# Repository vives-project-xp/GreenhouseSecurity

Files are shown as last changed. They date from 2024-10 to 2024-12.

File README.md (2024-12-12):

# Greenhouse Security

Op de site campus Brugge Xavarianenstraat komt een serre van 3x6m. Daarbij komt later ook nog een Tiny-house. Dit alles als IoT incubator voor project experience.   
Ons project zal zorgen voor de security en beveiliging van de serre. We maken hiervoor gebruik van bewakings camera's en een toegangs controle systeem.

# Inhoud
- [GreenhouseSecurity](#greenhousesecurity)
  - [Inhoud](#inhoud)
  - [Team](#team)
  - [Features](#features)
  - [Planning](#planning)
    - [Sprint 1](#sprint-1)
    - [Sprint 2](#sprint-2)
    - [Sprint 3](#sprint-3)
    - [Sprint 4](#sprint-4)
  - [Installatie Software](#installatie-software)
    - [Axis Camera Station](#axis-camera-station)
    - [Python](#python)
    - [Raspberry Pi](#raspberry-pi)
  - [Research](#research)
      - [Toegangssystemen](#toegangssystemen)
        - [NFC](#nfc)
        - [Authenticator](#authenticator)
        - [Biometrisch](#biometrisch)
      - [Camera's](#cameras)
        - [Axis](#axis)
        - [Stappenplan](#stappenplan)
        - [Privacy](#privacy)
      - [Project Affiche](#project-affiche)
  - [Het Project](#het-project)
        - [Installatie Camera's](#installatie-cameras)
        - [Installatie 360 Dome Camera](#installatie-360-dome-camera)
          - [3D-prints](#3d-prints)
        - [Installatie Fixed Camera](#installatie-fixed-camera)
          - [Montage](#montage)
      - [Installatie Toegangssysteem](#installatie-toegangssysteem)
        - [Code](#code)
  - [Integratie](#integratie)
  - [Pictogram:](#pictogram)
  - [Links](#links)
  - [Erkenningen](#erkenningen)
  - [BOM-Lijst](#bom-lijst)
  - [Research](#research)
# Team

- [Luca De Clerck](https://github.com/LucaClrk)  
- [Xander Claessens](https://github.com/xanderClaessens)   
- [Domien Verstraete](https://github.com/Belgianwafflecorp)

# Features
-  Security beelden van de serre
-  Mogelijkheid om security beelden overal te bekijken
-  Toegang tot serre controleren
-  Mogelijkheid om de deuren te sluiten
-  Geauthenticeerde toegang

# Planning
Onze planning kan je in detail bekijken op [Notion](https://www.notion.so/Project-Management-Tasks-Projects-Planning-15a7c97a744380f28060f6c136deb173?pvs=4).  
Maar hier zullen wij in grote lijnen alles plaatsen wat wij hebben gedaan en wat we zullen doen.  
## Planner
- ### Sprint 1
  - Architectuur document opgesteld
  - Axis Software testen
  - Camera functies testen
- ### Sprint 2
  - VM aanmaken
  - Code schrijven voor Raspberry Pi
  - Elektronisch schema uittekenen
- ### Sprint 3
  - Affiche maken
  - Starten PowerPoint
  - Motion Detection uittesten
  - Netwerk in orde stellen(VLAN)
  - Overleg wetgeving camera's
  - 3D-stukken printen
- ### Sprint 4
  -  Camera's installeren in serre
  -  Toegangssysteem installeren in serre
  -  Programma toegang afwerken
  -  Camera's en Raspberry Pi verbinden met netwerk
  -  Notificaties versturen bij motion detection

# Installatie Software
### Axis Camera Station
Ga naar de [Axis Camera station 5](https://www.axis.com/products/axis-camera-station/download) pagina om de nieuwste versie te downloaden. Hiermee ben je in staat de Axis camera's te beheren.
Het is belangrijk om de AXIS Camera Station Client MSI installer te installeren.  
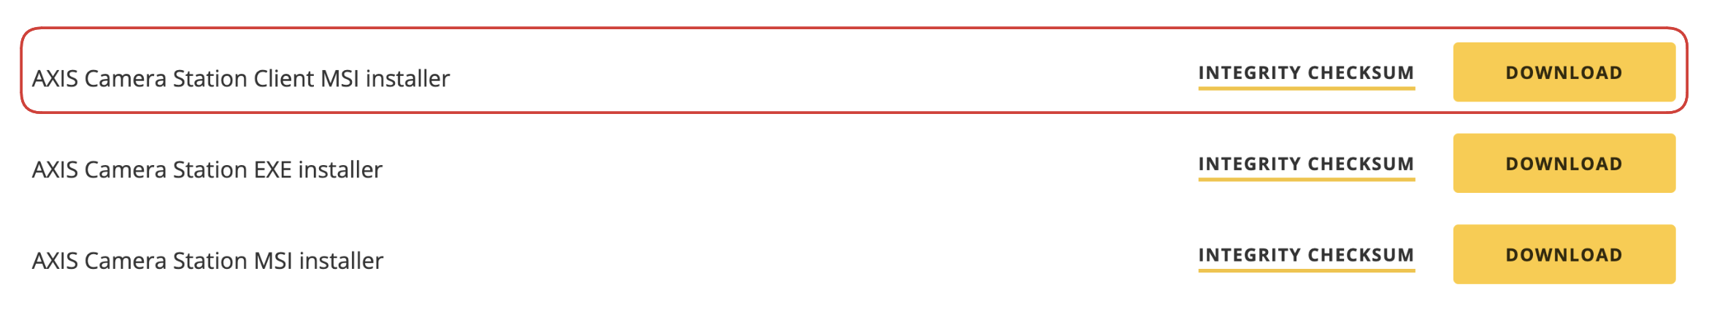
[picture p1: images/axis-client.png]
axis


### Python
Python kan je programmeren via [Visual Studio Code](https://code.visualstudio.com/download) of een andere IDE naar keuze. Bij gebruik van Visual Studio Code kan je de Python extensie installeren om zo te beginnen aan je Python programma.  
je drukt op de knop Extensions aan de linkerkant van je scherm. Dan krijg je een scherm van al de extensies.    
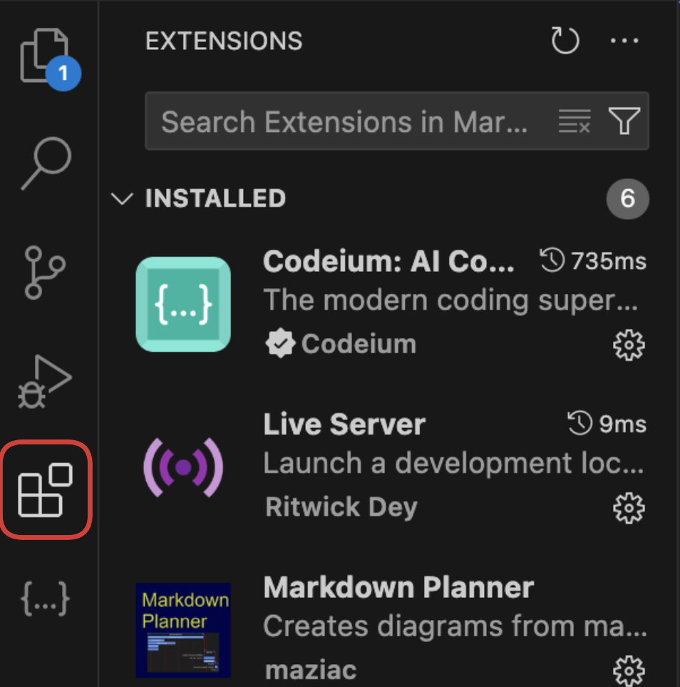
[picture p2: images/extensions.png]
  
Hierna kan je Python in typen in de zoekbalk. Dit geeft een lijst met alle extensies die te maken hebben met Python. Je zal de aangeduide versie willen installeren.  
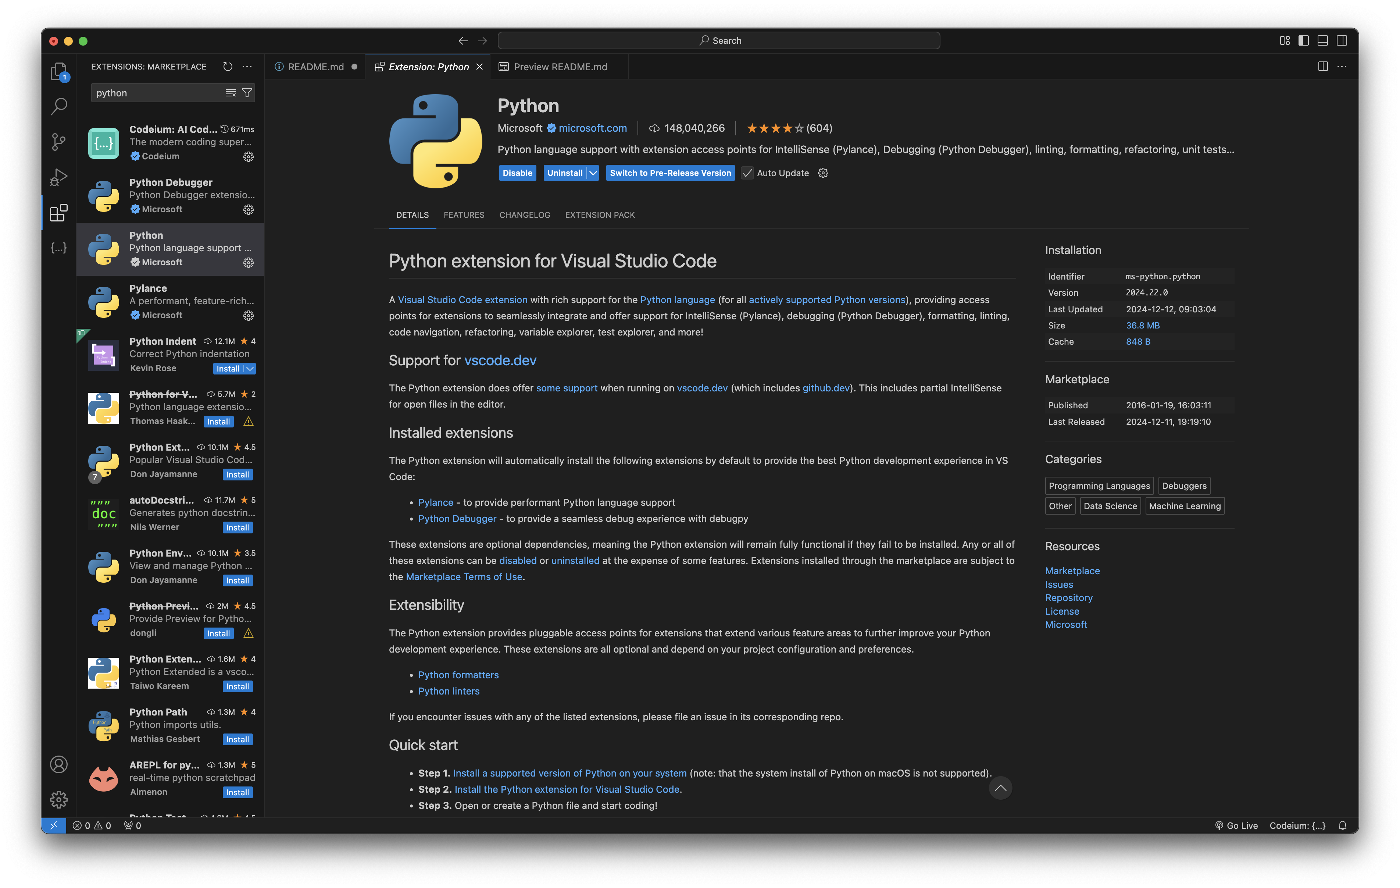
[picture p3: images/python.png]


### Raspberry Pi
Eerst en vooral moet je een [Raspberry Pi](https://www.raspberrypi.com/software/) aankopen. Als het mogelijk is een model 3 of hoger. Op de website heb je dan de mogelijkheid om de versie te installeren die past bij uw systeem.  
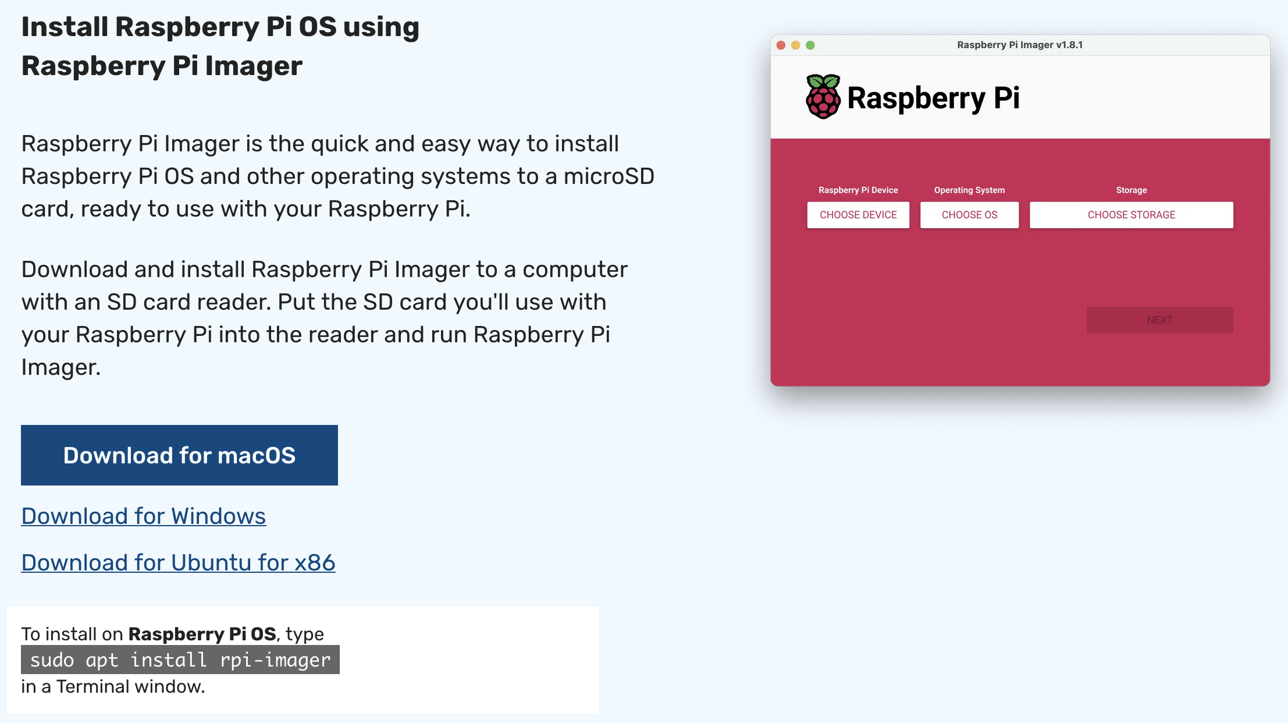
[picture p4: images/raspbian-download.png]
raspberry-pi
  
Hierna kan je via een SD kaart de [Raspberry Pi OS](https://www.raspberrypi.com/software/) installeren op je bordje. 
Via HDMI of DP, te zien welk bordje je hebt, kan je dan verbinden met de Raspberry Pi. 

# Research
  - ## Toegangsystemen:
    - ### NFC  
       NFC staat voor Near-Field Communication. Zoals de naam zelf verklapt is dit een manier om communicatie in te schakelen over een kleine afstand. Een set van communicatie protocollen maken het mogelijk om communicatie tussen elektronische apparaten in staat te stellen over een afstand van max 4cm.  
          Dit werkt met enerzijds een zend-/ontvangapparaat met een voeding en anderzijds een object met een chip en antenne, zoals een kaart, die gezamenlijk een NFC-tag hebben. De tag heeft geen voeding nodig omdat hij inductie energie ontvangt van het apparaat.  
          NFC wordt in veel toepassingen gebruikt. Denk aan betalingtransacties,sleutelhanger voor toegangscontrole...  

      NFC is dus een mogelijke optie voor toegangscontrole tot de serre. Je kan dan met een NFC-tag de serre openen. Bijvoorbeeld aan de hand van je GSM en een simpele RFID-chip.  
    - ### Authenticator  
        Een authenticator is ook een manier om toegangscontrole toe te passen. Denk aan de google authenticator die je constant codes geeft die veranderen. Dit zorgt voor een veilige manier van toegangscontrole omdat je "wachtwoord" tot de serre voor iedereen anders is en constant verandert. Ook is er geen nood aan een kaart of dergelijke, die je mogelijks kan verliezen.  
    - ### Biometrisch  
        Biometrie betekent letterlijk "meten van de levenden" en verwijst in een hele brede zin naar de studie van levende wezens. Wij zullen deze studies toepassen om een biometrisch toegangscontrole systeem te maken.  
        Biometrie kan je "meten", denk aan je vingerafdruk, irispatroon, gelaatstrekken of DNA. Wij zullen niet zo ver gaan als DNA, maar iets zoals je vingerafdruk kan zeker zorgen voor een goeie beveiliging.
        Een toegangskaart of tag zoals bij NFC kan je verliezen, je vinger zal je niet zo rap verliezen.
        Jammer genoeg zullen zij niet aan biometrie doen omdat deze gegevens moeten opgeslaan worden. Door de privacy wet mogen wij dit soort gegevens niet opslaan.

- ## Camera's
    - ### Axis   
      Wij werden Axis camera's aangeboden van de opleiding Elektronica-ICT. Axis is een Zweedse manufacturer die zich spezialiseert in het verkopen van camera's, access control en netwerk audio apparaten voor bedrijven. We werken dus met een high end camera systeem die bedoelt is voor industriële bedrijven. Deze camera's komen met geïntegreerde software en software van Axis zelf die we kunnen gebruiken voor heel wat doeleinden.  
      Met de software zijn we in staat om beelden te streamen, op te nemen en zelfs motion detection toe te passen.
    - ### Stappenplan  
      Het is heel gemakkelijk om deze apparaten operationeel te maken.  
      Installeer eerst de Axis Software die u nodig acht voor het gebruik van de camera's. Wij hebben hiervoor Axis Camera Station 5 gebruikt.  
      Plug de camera's in via Ethernet in je netwerk en na een paar minuten zouden deze moeten verschijnen in de applicatie.  
      In de applicatie kan u dan kiezen wat u met deze camera's wilt doen. Het is wel belangrijk dat je op hetzelfde netwerk zit als de camera's.
    - ### Privacy  
      Omtrent de wet van de privacy zijn er heel wat wettem over het gebruik van camera's. Uiteraard moeten wij met al deze wetten rekening houden tijdens het maken van dit project.  
      Om dit te verduidelijken kan u een kijkje nemen in ons document "[info](./Wetgeving/info.md)".

    - ### Melding wanneer iemand het gebied betreed of inlogt
        - SMS
        - Mail

# Project Affiche
Voor het project werden wij gevraagd om een affiche te maken. Deze affiche bevat de titel van het project, een korte beschrijving, de vaardigheden die werden gebruikt voor het project te realiseren een paar foto's. Met dit affiche is het de bedoeling om ons project zo aantrekkelijk mogelijk te maken en gemakkelijk uit te leggen over wat dit gaat.  

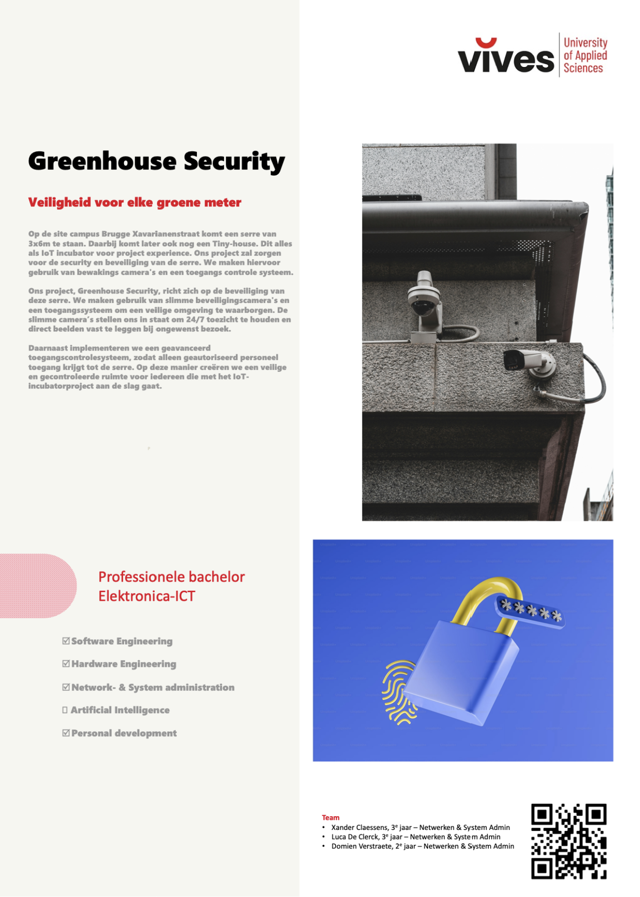
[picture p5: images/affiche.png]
affiche
  

# Het Project  
Na dat het research is gebeurd, kunnen we beginnen met het project. Omdat de serre er in het begin van het semester nog niet stond konden we niet onmiddellijk een oplossing bedenken van hoe we de camera in de serre zouden plaatsen, of hoe we het toegangsysteem zouden opzetten in de serre. Maar dit heeft ons niet tegengehouden en we zijn toch begonnen met ideeën hiervoor.
## Camera's
We zijn begonnen met de camera's te testen via de Axis Camera Station software. Hier waren we er ook al snel achter gekomen dat er motion detection kon toegepast worden met deze software. Samen met Home Assistant hadden we dan de mogelijkheid om mails te sturen wanneer de camera beweging detecteerde. Om het netwerk niet te belasten moest er een aparte VLAN aangemaakt worden voor de camera's. Naast dit moest er ook een VM aangemaakt worden die ervoor zorgt dat we deze camera beelden overal kunnen bekijken. Deze VM moet dan logischer wijs ook in VLAN 12 terecht komen.  

Na dat de serre geplaatst werd konden we dan ook beginnen nadenken over hoe we deze camera in de serre konden plaatsen.
### Installatie Camera's  

-  #### Installatie 360 Dome Camera
      Om de camera in de serre te plaatsen hebben wij 3D-stukken aangevraagd. Deze 3D-prints hebben wij zelf getekend in AutoDesk Inventor.  

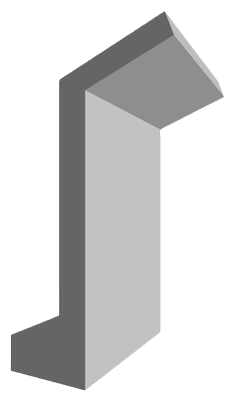
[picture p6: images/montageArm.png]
      
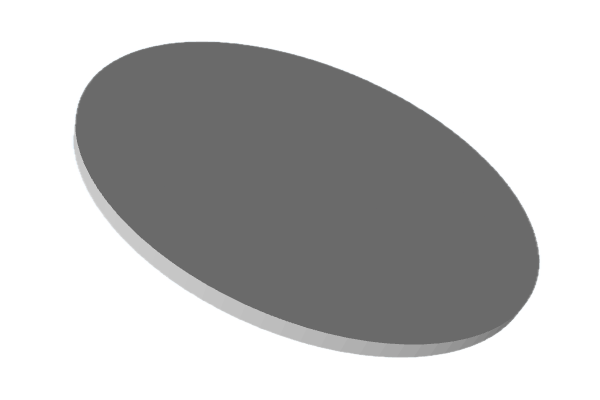
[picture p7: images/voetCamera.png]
          
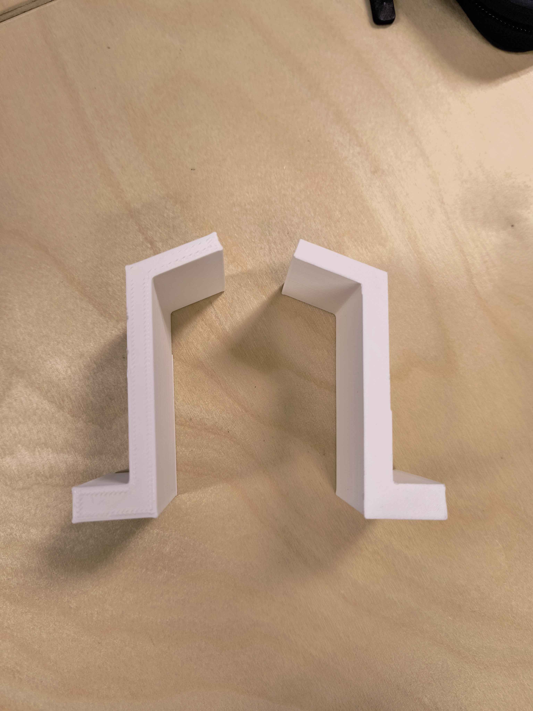
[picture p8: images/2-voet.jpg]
        
      
      De arm stukken zullen we gebruiken om te monteren aan het dak. De voet kunnen we dan monteren aan deze armen. Na deze installatie kunnen we gemakkelijk de camera aan de voet monteren voor een stabiele installatie.  

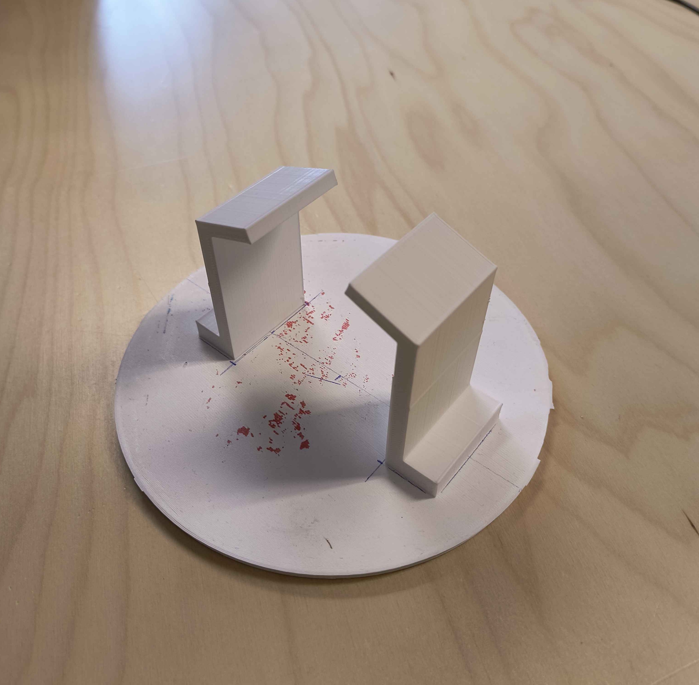
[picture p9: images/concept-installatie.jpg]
        
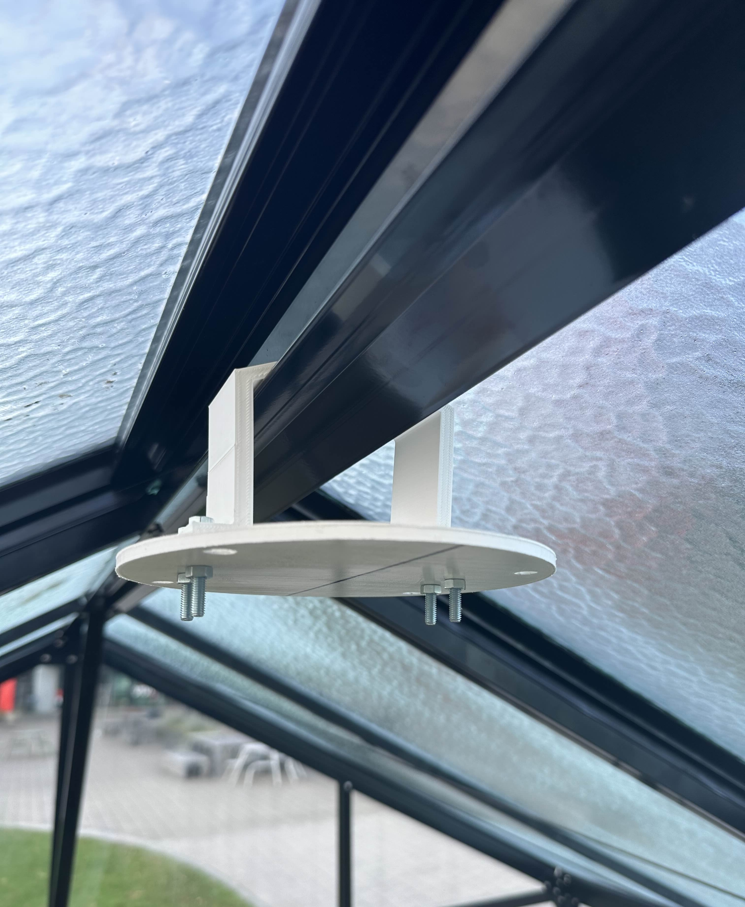
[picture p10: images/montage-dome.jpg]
      

-  ### Installatie Fixed Camera
    De fixed camera komt op het dak te staan. Om dit te doen hebben we iets stevig nodig om de camera te monteren. Dit stuk zal ook tegen de diverse weersomstandigheden bestand moeten zijn.  
    Daarom hebben wij geopteerd voor bandijzer. Dit is een plaat ijzer met gaten in die buigbaar en waar je kan door boren.   
    Dit bandijzer hebben wij zo geplooid dat dit op de railing van het dak zal komen. Dit zal er zo uitzien :

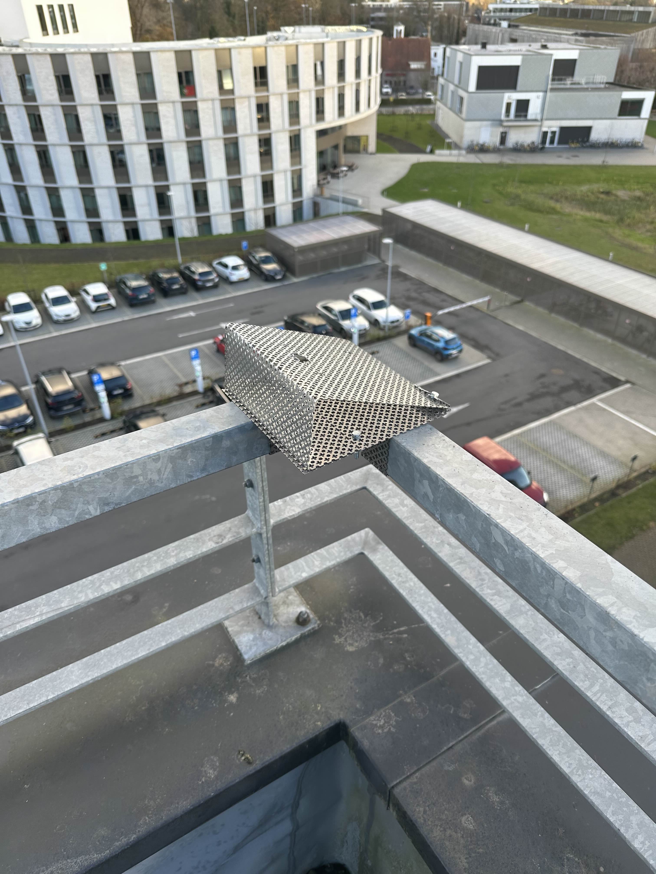
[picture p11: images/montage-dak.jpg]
bandijzer
      

Na dat de installaties gebeurd zijn, konden we beginnen met de beelden op een scherm te krijgen in het lokaal. Hiervoor hebben we een PC geboot met Windows 10. Hierop installeerden we dan de Axis software waardoor we de camera beelden te zien kregen.  
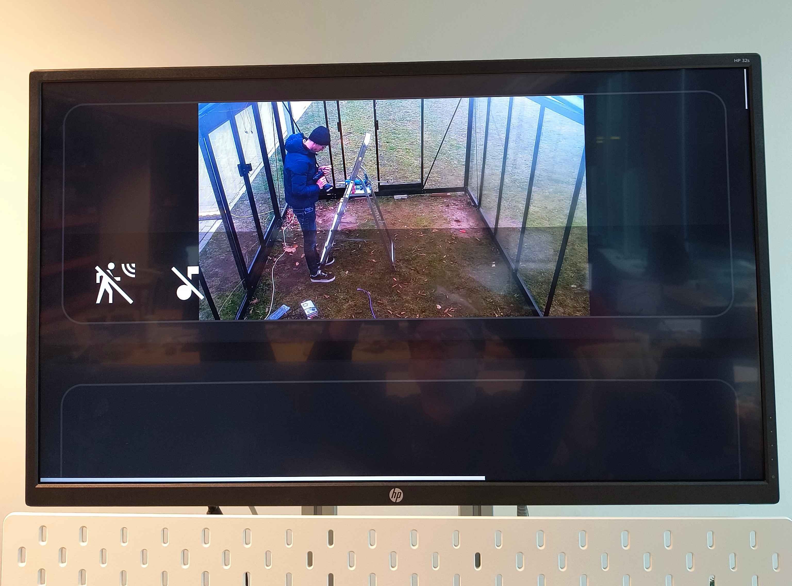
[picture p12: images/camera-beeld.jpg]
  

Na commentaar van het hoofd van de infrastructuur werd ons verteld dat de camera op het dak weg moest. Hier hebben wij jammer genoeg dus geen beelden van.

## Toegangsysteem
Na de verschillende toegangsystemen te bestuderen hebben wij besloten om een authenticator te gebruiken. Met de Google authenticator krijg je een code, deze code moet dan met een numeriek ingegeven worden. Na dat deze code ingegeven wordt worden de deuren geopend.
### Installatie Toegangssysteem
  Om het toegangssysteem te installeren gebruiken wij 4 solenoïden die als een slot werken voor de deuren. Een solenoide is een pin die geactiveerd wordt als deze onder spanning komt te staan.
  Hij doet dat aan de hand van een veer.  
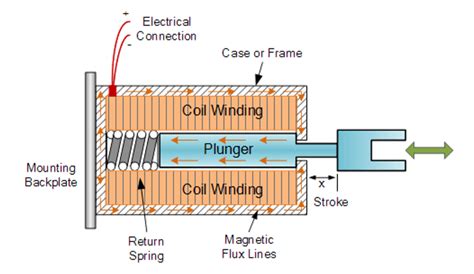
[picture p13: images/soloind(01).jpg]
    
  De deuren van de serre zijn schuifdeuren, hierdoor hebben wij geopteerd om deze sloten telkens aan de onderkant te plaatsen. Hierdoor kan je de deur niet openen als het slot niet naar beneden is.
  De solenoïden worden aangestuurd via een relais. Je kunt ervoor kiezen om deze normally closed of normally open te hebben. Wij zouden opteren voor normally closed zodat ze niet constant onder spanning komen te staan.  
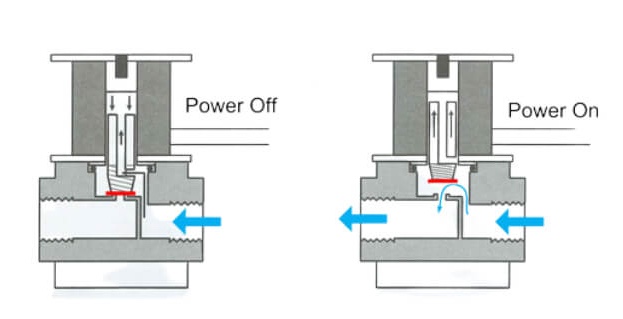
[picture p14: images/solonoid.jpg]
solonoid
    
  Na dat de code dan ingegeven wordt, wordt via de elektronische schakeling de pinnen geschakeld waardoor de deuren geopend worden.

### Code
  In de [Setup](./Documenten/setup.md) file Kan je lezen welke libraries u zal nodig hebben om het programma te schrijven.  
  Met dit programma gebruiken we user input van het numeriek toegangsbordje. Met deze input kunnen we verifiëren als deze persoon wel toegang heeft tot de serie en kunnen we de deuren gesloten of geopend zetten.  
  Als je de volledige code wil bekijken kan je dit vinden in de [Code](Code/Authenticator/) folder.  

# Integratie
De serre bestaat niet alleen voor het project Security. Er zijn nog heel wat andere projecten die ook rond de serre gaan. Het is dan belangrijk om ervoor te zorgen dat al deze projecten samen kunnen werken.  
Hiermee wordt dan bedoelt dat deze projecten op hetzelfde netwerk werken, elkaar niet storen en als 1 geheel werkt.  
In deze topic zullen we uitleggen hoe wij ervoor zorgen dat ons project geïntegreerd is zodat het kan samenwerken met alle andere projecten.  

Het project Home-Assistant zal ervoor zorgen dat er een netwerk aanwezig is in de serre. Dit netwerk zal ons in staat stellen om de gebruikte camera's voor het project te verbinden met dit netwerk.  
Door dit te doen heeft Home-Assistant de mogelijkheid om de camera beelden te bekijken op hun applicatie. Op deze manier is ons project geïntegreerd met de andere projecten, want home-assistant zorgt voor de integratie van alle projecten.

# Pictogram:
Verplicht pictogram met aanduiding dat er camera bewaking aanwezig is.
Dit staat in het Koninklijk besluit dat dit zo moet (zie links voor meer info). 

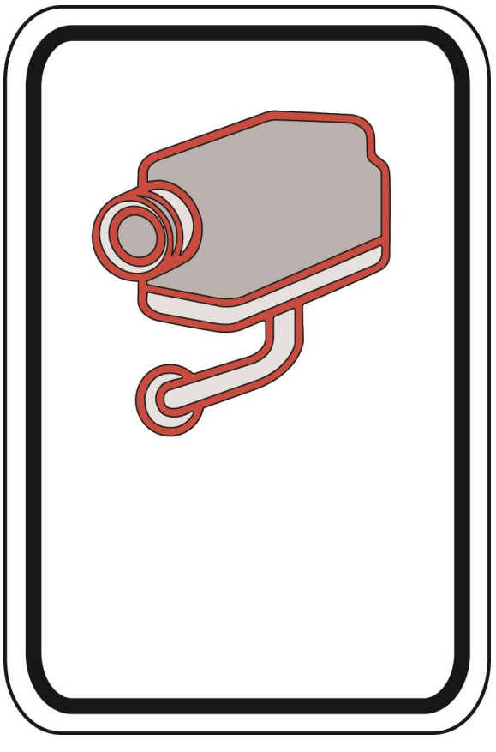
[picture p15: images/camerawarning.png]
camera sticker


# Links
- [Info](https://acd.eu/producten/r308-xh-blackline/)
- [Koninklijk Besluit](https://www.besafe.be/sites/default/files/2022-08/ar_pictogramme_-_version_coordonnee_avec_modif_2020.pdf) 
- [Info](https://www.besafe.be/nl/bewakingscamera/pictogram)
- [Klein pin slot](https://www.credexalarmsystems.eu/nl/eb-004-conas-electric-bolt-lockfor-automatic-doors-failsafe.html)
- [2-kanaals 3V relais module](https://www.kiwi-electronics.com/nl/2-kanaals-3v-relais-module-20106?search=relais)
- [Koninklijk Besluit](https://www.besafe.be/sites/default/files/2022-08/ar_pictogramme_-_version_coordonnee_avec_modif_2020.pdf) 
- [Info](https://www.besafe.be/nl/bewakingscamera/pictogram)
- [Klein pin slot](https://www.credexalarmsystems.eu/nl/eb-004-conas-electric-bolt-lockfor-automatic-doors-failsafe.html)
- [Keypad info](https://learn.adafruit.com/matrix-keypad?view=all)
- [Axis OS](https://www.axis.com/products/axis-camera-station/download) 

# Erkenningen

- [Info](https://acd.eu/producten/r308-xh-blackline/)
- [Koninklijk Besluit](https://www.besafe.be/sites/default/files/2022-08/ar_pictogramme_-_version_coordonnee_avec_modif_2020.pdf) 
- [Pictogram](https://www.besafe.be/nl/bewakingscamera/pictogram)
- [Klein Pin Slot](https://www.credexalarmsystems.eu/nl/eb-004-conas-electric-bolt-lockfor-automatic-doors-failsafe.html)

# BOM-Lijst

| Beschrijving | Hoeveelheid | Prijs (€) |
|---|---|---|
| Raspberry pi | 1 | 61,95 |
| Nummeriek | 1 | 7,34 |
| Pictogram | 1 | 2,39 |
| Push-pull solenoids | 4 | 47,80 |
| Montage stukken  | 4 | 9,16 |
| Kables | 7 | 12.39 |
| Aftakdoos | 1 | 12.79 |
| Relais module | 1 | 11.90 |
| Tapbout met moer | 1 | 7,99 |
| Fastener met draadeind | 1 | 3,99 |
| **Total Price** | - |  |

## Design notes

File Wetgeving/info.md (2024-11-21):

##  Belangrijkste stappen die we moeten ondernemen om camera's te mogen ophangen:
### We zitten met 2 situaties waar we rekening mee moeten houden en die zijn:
    - camera wetgeving
    - camera op werkplaats

- Doelstelling vastleggen: De school moet een duidelijke doelstelling hebben voor de camerabewaking. Dit kan bijvoorbeeld het beveiligen van eigendommen, het beschermen van personen, of het voorkomen van diefstal of vandalisme zijn. De camera’s mogen niet gebruikt worden voor toezicht op personeel of studenten zonder een geldige reden.

- Camerabewakingswet: In België is de Camerabewakingswet van toepassing. Volgens deze wet moet de school de plaatsing van de camera's melden bij de Lokale Politie en moet ze een aangifte doen via het [E-loket](www.aangiftecamera.be) van de FOD Binnenlandse Zaken.

- GDPR (General Data Protection Regulation): Camerabeelden kunnen als persoonsgegevens worden beschouwd. De school moet de GDPR-regels volgen en ervoor zorgen dat de gegevensverwerking rechtmatig, transparant en in overeenstemming met de wet gebeurt. Dit houdt in dat:

- De school een verwerkingsregister bijhoudt.
Camerabeelden alleen worden bewaard voor de noodzakelijke duur (meestal maximaal 30 dagen).
Er een verwerkersovereenkomst is als de beelden door een extern bedrijf worden beheerd.
Informatieplicht (bordje hangen): De school moet mensen die het gebouw betreden informeren over de camerabewaking. Dit gebeurt door het ophangen van een pictogram dat aangeeft dat er camera's hangen, met daarbij de contactgegevens van de verantwoordelijke voor de verwerking van de beelden.

- Raadpleging van de ondernemingsraad of vakbonden: Als de camera's ook personeelsleden zullen opnemen, moet de school de ondernemingsraad of personeelsvertegenwoordiging raadplegen, aangezien dit betrekking heeft op de werkvloer.

- Vergunningen: In de meeste gevallen is er geen specifieke vergunning nodig voor het ophangen van bewakingscamera's, maar dit kan verschillen per gemeente. Het is verstandig om dit te controleren bij de lokale overheid.

### Samenvatting van de stappen:
1. Aangifte doen bij de politie (voor elke camera).
2. Overleg met werknemers (voor camera’s op de werkplek).
3. Pictogrammen en informatieborden plaatsen.
4. Recht op toegang tot beelden waarborgen.
5. Veilige opslag en bewaartermijn van maximaal 1 maand.
6. Informatieplicht naar betrokkenen (GDPR).

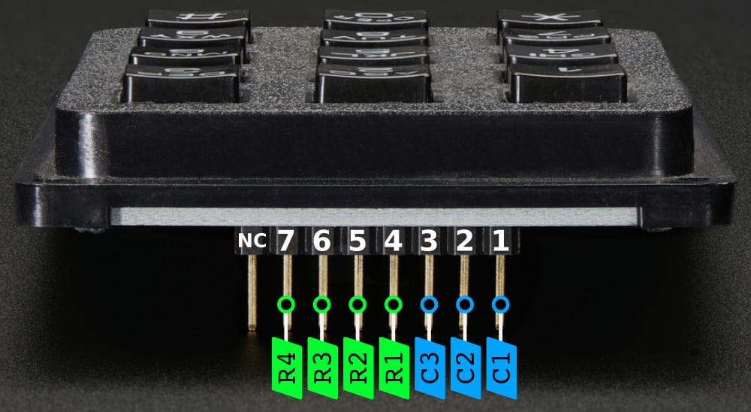
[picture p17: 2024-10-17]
images/KeypadPinOuts.jpg

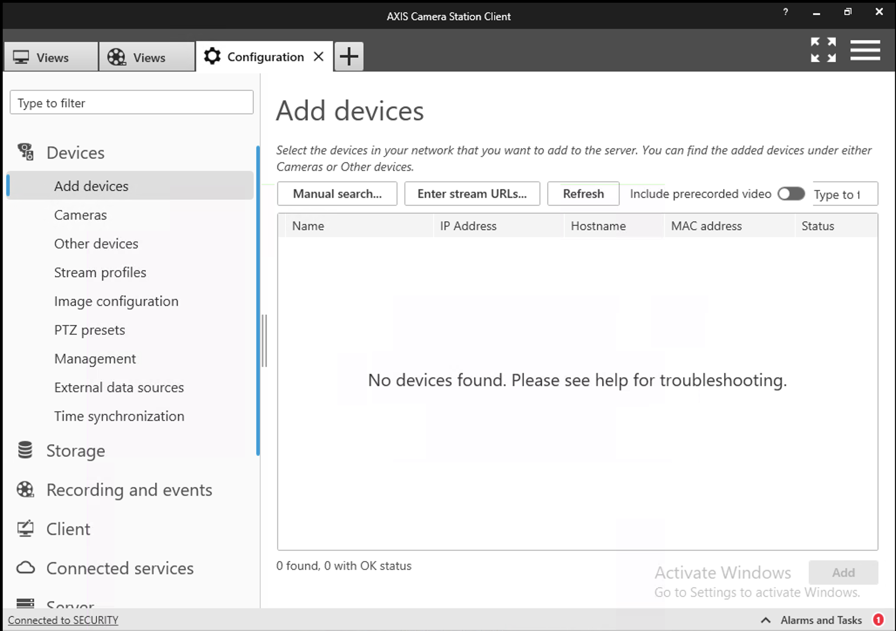
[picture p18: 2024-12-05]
images/axis-application.png

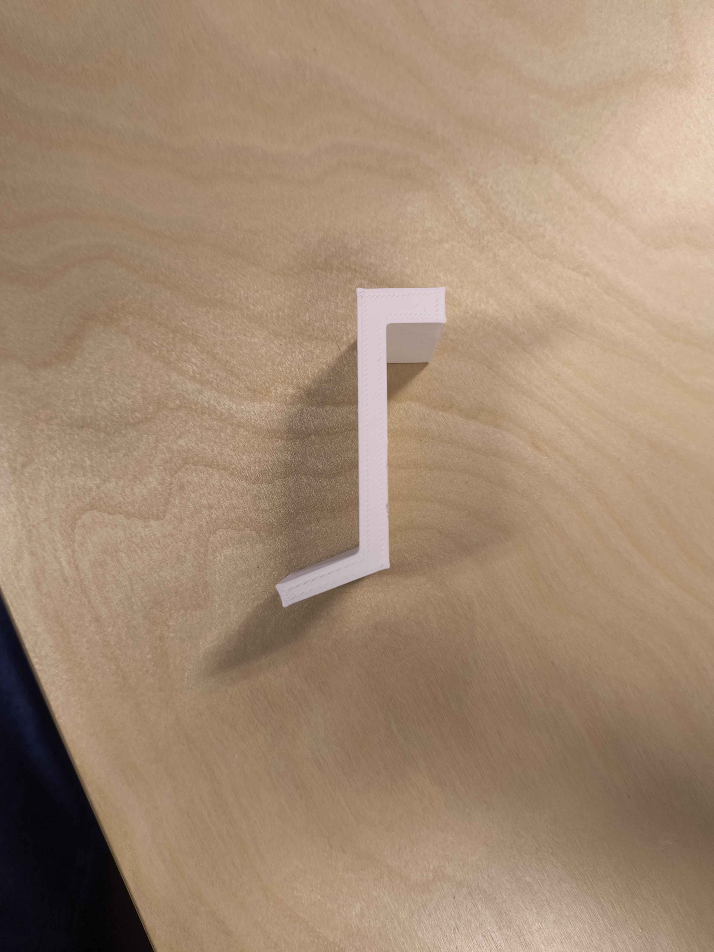
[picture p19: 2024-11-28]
images/voet-boven.jpg

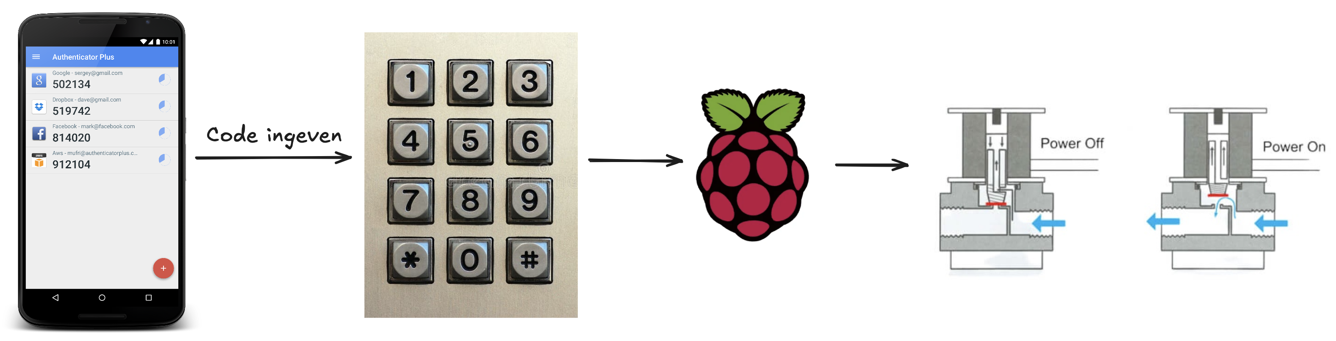
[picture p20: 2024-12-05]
images/authenticator-excalidraw.png

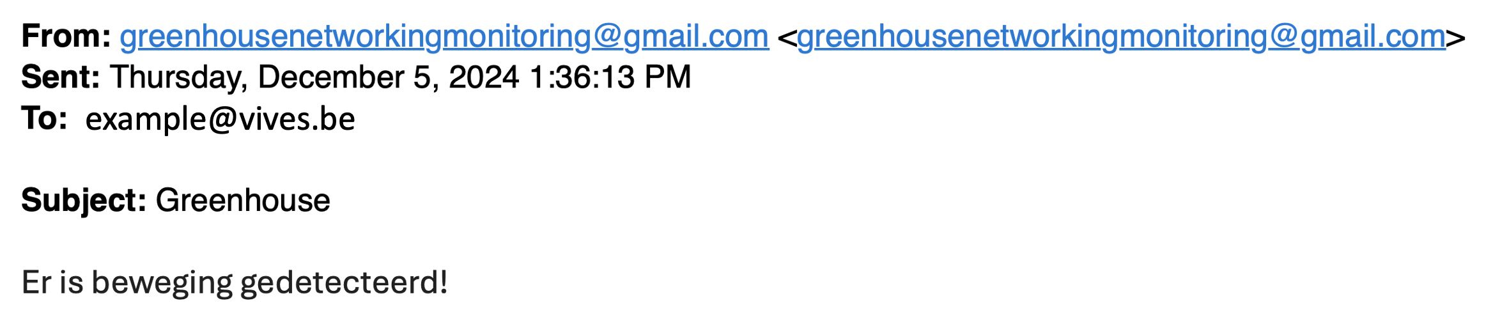
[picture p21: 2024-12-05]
images/notification-email.png

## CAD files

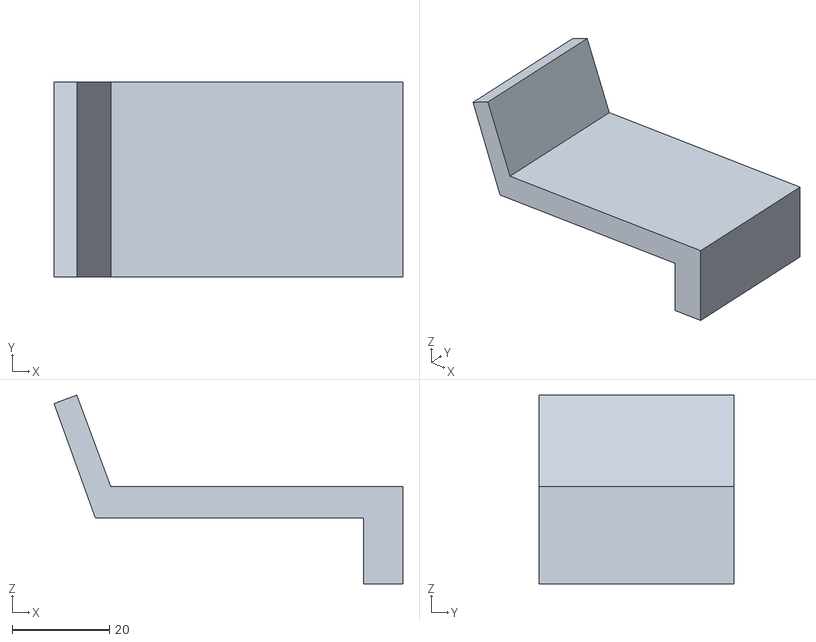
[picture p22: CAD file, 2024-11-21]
3D-prints/montageArm.stl
71.7 x 40.0 x 38.7

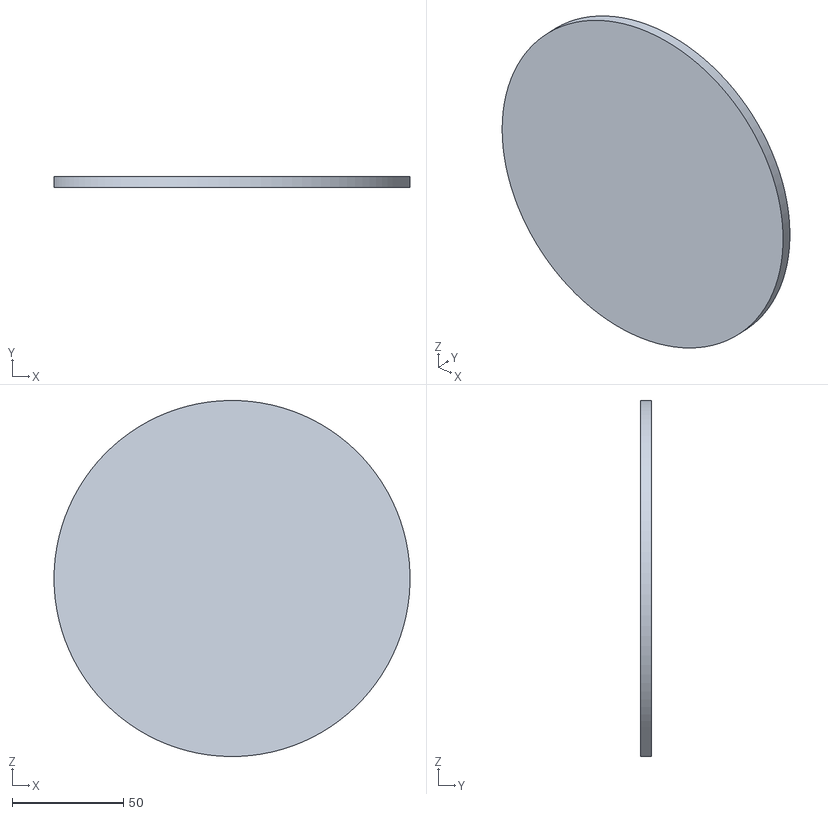
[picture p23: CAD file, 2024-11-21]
3D-prints/voetCamera.stl
160.0 x 5.00 x 160.0

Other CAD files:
3D-prints/montageArm.ipt
3D-prints/voetCamera.ipt

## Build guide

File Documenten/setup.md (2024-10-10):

# Opzetten van authenticatie op raspberry:

## Updaten:

```sh
sudo apt update
sudo apt upgrade

```

## installeren packages:

```sh
sudo apt install python3-pyotp
sudo apt install python3-qrcode
sudo apt install python3-rpi.gpio
sudo pip install pad4pi --break-system-packages

```

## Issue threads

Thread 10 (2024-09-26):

Opzoekwerk slot

xanderClaessens, 2024-09-26:
Welk slot past het beste en lukt het beste met onze toepassing

xanderClaessens, 2024-10-03:
We hebben meer info gekregen, we moeten niet meer de deuren doen van de serre, er zou een omheining komen waar we de toegang van doen, dit zal waarschijnlijk zijn met een pomp ofs die we dan aansturen met onze raspberry, of via een relais

Closed 2024-10-10.

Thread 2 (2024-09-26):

Research wetgeving

Belgianwafflecorp, 2024-09-26:
Camerawet (Wet van 21 maart 2007): Camera's moeten worden aangemeld bij de
lokale politie en gemarkeerd met waarschuwingsbordjes. De opnames mogen enkel
gebruikt worden voor beveiligingsdoeleinden en moeten binnen 30 dagen worden gewist,
tenzij er een incident is waarbij de beelden als bewijs dienen.

GDPR (AVG): Beelden van personen zijn persoonsgegevens en moeten conform de AVG
worden behandeld. Er moeten duidelijke richtlijnen zijn over wie toegang heeft tot de
beelden, de bewaartermijn, en hoe de beelden worden beveiligd tegen ongeoorloofde
toegang.

Belgianwafflecorp, 2024-09-26:
Camera wetgeving: https://www.besafe.be/nl/camerawet

Privacy wetgeving: https://www.gegevensbeschermingsautoriteit.be/burger/thema-s/camera-s-en-uw-privacy/ander-cameragebruik

Aangifte bewakings camera: http://www.aangiftecamera.be/

Closed 2024-10-03.

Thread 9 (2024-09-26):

camera resetten

Belgianwafflecorp, 2024-09-26:

Belgianwafflecorp, 2024-09-26:
https://www.youtube.com/watch?v=1DbRHC2DWuY

Closed 2024-09-26.

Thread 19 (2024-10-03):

Numeriek zoeken

xanderClaessens, 2024-10-03:
Numeriek zoeken die waterdicht, draadloos en bedraad kan werken.

xanderClaessens, 2024-10-03:
We zullen voor een plaat kiezen om de numeriek te bevestigen zo is er geen probleem met een schuifdeur

Belgianwafflecorp, 2024-10-03:
https://www.kiwi-electronics.com/nl/3x4-phone-style-matrix-keypad-2907?search=keypad%20matrix

Closed 2024-10-03.

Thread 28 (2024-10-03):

Bericht krijgen bij beweging op camera

xanderClaessens, 2024-10-03:
We zoeken hoe we een bericht kunnen krijgen via sms, mail of nog iets anders als er beweging is gedetecteerd op de camera

Belgianwafflecorp, 2024-10-10:
Deze issue is dubbel (#23)

Belgianwafflecorp, 2024-10-17:
https://www.axis.com/dam/public/8d/45/26/notification-messages-en-US-41871.pdf

Belgianwafflecorp, 2024-10-17:
Guide to setup event triggers:
https://www.axis.com/dam/public/8d/45/26/notification-messages-en-US-41871.pdf

Belgianwafflecorp, 2024-10-17:
Yt video to setup notifications:
https://www.youtube.com/watch?v=PRCT5Xr5F9A

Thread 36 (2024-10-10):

Bespreking ter plaatse

Belgianwafflecorp, 2024-10-10:
Samen met project coach op de site waar de serre komt overleggen wat er verwacht wordt.

Belgianwafflecorp, 2024-10-10:
Serre komt op het dak te staan.
Er moet een 360° camera in de serre geplaatst worden.
De serre moet toegangs authenticatie met slot worden voorzien.
Dit op beide dubbele schuifdeuren.

Closed 2024-10-10.

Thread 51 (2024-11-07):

Solar powered camera pole research

Belgianwafflecorp, 2024-11-07:

Belgianwafflecorp, 2024-11-07:
https://www.lsvisionsolar.com/which-one-is-better-solar-powered-camera-or-ip-camera/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,with%20a%20solar%20system%20installed.

Belgianwafflecorp, 2024-11-07:
Mount idea:
https://www.sunshinesolar.co.uk/Item/FS_360PM

Closed 2024-11-07.

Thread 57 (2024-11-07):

Ingesloten probleem

Belgianwafflecorp, 2024-11-07:
Als iemand in de serre komt en de deur sluit, sluiten de slagpinnen.
Er moet een drukknop aan de binnenkant komen om de deuren van binnenuit te kunnen ontgrendelen.
Of een ander systeem die dit probleem voorkomt.

Closed 2024-11-07.

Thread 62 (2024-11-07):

VLAN VM werkt niet

LucaClrk, 2024-11-07:
Door het hoge netwerk trafiek die de camera's genereren, moeten we de VM voor de camera's op een aparte VLAN steken. Maar de VLAN die ons werd toegewezen werkt niet waardoor het niet lukt om de Windows VM te booten.

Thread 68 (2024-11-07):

Overleggen met mannen van netwerk

xanderClaessens, 2024-11-07:
Zij kunnen blijkbaar op homeassistant een melding zien dat er beweging is, wij kunnen dit niet zien via de software en zetten alarm aan maar zien niets passeren bij ons. De mannen van het netwerk zullen dan de melding naar ons doorsturen.

Closed 2024-11-28.

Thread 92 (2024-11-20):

Probleem wanneer moeten slagpinnen toe?

xanderClaessens, 2024-11-20:
moet de slagpin wel toe als de persoon in de sere is? wat als we ze nu op de # van het 3x4 laten klikken om ze weer te laten ingaan? of we kunnen de knop binnen gebruiken om ze in te schakelen en uitschakelen?

Closed 2024-12-05.

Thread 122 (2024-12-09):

Pin pi werkt niet

xanderClaessens, 2024-12-09:

xanderClaessens, 2024-12-09:
De pin relay werkt omgekeerd, hij schakelt als de pin laag is. Dus gewoon naar normally open veranderen om de draden van de slagpinnen te onderbreken.

Closed 2024-12-09.

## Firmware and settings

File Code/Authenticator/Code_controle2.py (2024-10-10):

import pyotp
import RPi.GPIO as GPIO  #is alleen voor raspberry pi
import time

# GPIO setup
RELAIS_PIN = 18
GPIO.setmode(GPIO.BCM)
GPIO.setup(RELAIS_PIN, GPIO.OUT)

# Het geheime wachtwoord dat overeenkomt met de Google Authenticator QR-code
secret = "JBSWY3DPEHPK3PXP"  # Dit moet hetzelfde geheim zijn als in je QR-code!
totp = pyotp.TOTP(secret)

def open_deur():
    GPIO.output(RELAIS_PIN, GPIO.HIGH)  # Zet relais aan
    print("Deur is open voor 5 seconden...")
    time.sleep(5)  # Deur open voor 5 seconden
    GPIO.output(RELAIS_PIN, GPIO.LOW)   # Zet relais uit
    print("Deur is nu gesloten.")

def main():
    while True:
        # Vraag de gebruiker om een code in te voeren
        ingevoerde_code = input("Voer uw code in (of type 'exit' om te stoppen): ")

        if ingevoerde_code.lower() == 'exit':
            print("Programma gestopt.")
            break

        # Verifieer de TOTP-code
        if totp.verify(ingevoerde_code):
            print("Toegang verleend!")
            open_deur()
        else:
            print("Toegang geweigerd! Verkeerde code.")

if __name__ == '__main__':
    try:
        main()
    except KeyboardInterrupt:
        print("\nProgramma onderbroken door gebruiker.")
    finally:
        GPIO.cleanup()  # Zorg ervoor dat de GPIO netjes wordt afgesloten

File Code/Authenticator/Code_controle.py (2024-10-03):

from flask import Flask, request, jsonify
import pyotp

# Setup Flask app
app = Flask(__name__)

# Het geheime wachtwoord dat overeenkomt met de Google Authenticator QR-code
secret = "JBSWY3DPEHPK3PXP"  # Dit moet hetzelfde geheim zijn als in je QR-code!
totp = pyotp.TOTP(secret)

# Endpoint om de code te verifiëren
@app.route('/verify', methods=['POST'])
def verify_code():
    data = request.get_json()
    ingevoerde_code = data.get('code')

    if not ingevoerde_code:
        return jsonify({"status": "error", "message": "Code ontbreekt"}), 400
    
    # Verifieer de TOTP-code
    if totp.verify(ingevoerde_code):
        print("Toegang verleend!")
        return jsonify({"status": "success", "message": "Toegang verleend!"}), 200
    else:
        print("Toegang geweigerd!")
        return jsonify({"status": "error", "message": "Toegang geweigerd!"}), 403

# Start de server
if __name__ == '__main__':
    app.run(host='0.0.0.0', port=5000)

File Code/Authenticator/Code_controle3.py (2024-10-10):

import RPi.GPIO as GPIO #is alleen voor raspberry pi
import time
import pyotp
from pad4pi import rpi_gpio #is alleen voor raspberry pi

# GPIO setup for the relay
RELAIS_PIN = 18
GPIO.setmode(GPIO.BCM)
GPIO.setup(RELAIS_PIN, GPIO.OUT)

# Het geheime wachtwoord dat overeenkomt met de Google Authenticator QR-code
secret = "JBSWY3DPEHPK3PXP"
totp = pyotp.TOTP(secret)

# Keypad setup
KEYPAD = [
    ['1', '2', '3', 'A'],
    ['4', '5', '6', 'B'],
    ['7', '8', '9', 'C'],
    ['*', '0', '#', 'D']
]

ROW_PINS = [5, 6, 13, 19]  # GPIO pinnen verbonden met de rijen van het keypad
COL_PINS = [26, 16, 20, 21]  # GPIO pinnen verbonden met de kolommen van het keypad

factory = rpi_gpio.KeypadFactory()
keypad = factory.create_keypad(keypad=KEYPAD, row_pins=ROW_PINS, col_pins=COL_PINS)

# Variabele om de code op te slaan
code = ""

def open_deur():
    GPIO.output(RELAIS_PIN, GPIO.HIGH)  # Zet relais aan
    print("Deur is open voor 5 seconden...")
    time.sleep(5)
    GPIO.output(RELAIS_PIN, GPIO.LOW)   # Zet relais uit
    print("Deur is nu gesloten.")

# Callback-functie voor wanneer een toets wordt ingedrukt
def keypad_press(key):
    global code
    print(key)
    
    if key == '#':  # # om de code te bevestigen
        print(f"Code ingevoerd: {code}")
        if totp.verify(code):
            print("Toegang verleend!")
            open_deur()
        else:
            print("Toegang geweigerd! Verkeerde code.")
        code = ""  # Reset de code na invoer
    elif key == '*':  # * om de code te resetten
        code = ""
        print("Code gereset.")
    else:
        code += key  # Voeg de ingedrukte toets toe aan de code

# Keypad listener
keypad.registerKeyPressHandler(keypad_press)

try:
    while True:
        time.sleep(0.1)  # Houd het programma draaiende
except KeyboardInterrupt:
    print("\nProgramma gestopt.")
finally:
    GPIO.cleanup()  # GPIO netjes afsluiten
    keypad.cleanup()  # Keypad netjes afsluiten

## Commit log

2024-10-03 BOM lijst
2024-10-10 BOM lijst aanvullen
2024-10-10 BOM lijst prijzen
2024-10-17 keypad pin out info
2024-11-21 3d parts auto cad
    [montageArm.ipt, voetCamera.ipt]
2024-11-21 Adding stl files
    [montageArm.stl, voetCamera.stl]
2024-11-28 Foto's toevoegen van 3D-prints
2024-11-28 Toevoegen van het 3D-gedeelte
2024-11-28 Toevoegen van de montage in de README
2024-12-05 Powerpoint uploaden
2024-12-12 Deel camera in de README
